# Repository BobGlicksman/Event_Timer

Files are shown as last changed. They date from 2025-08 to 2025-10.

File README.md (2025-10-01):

# Event_Timer
Device to automatically publish Particle events based upon time-based schedules.

## OVERVIEW.
The Event Timer is a standalone component that is intended to be used to automate other projects that are based upon Particle (particle.io) IoT devices.  The Event Timer keeps accurate local time and can run very complex schedules for time-based events.  Upon reaching the date/time for each event, the Event Timer publishes an event to the Particle Cloud.  Particle-based subscribers can then subscribe to the published event and execute a suitable function based upon the event’s data.

The Event Timer software uses the Particle *LocalTimeRK* library to handle all of the complexities of timekeeping, timezone and DST conversion, flexible scheduling, and schedule management.  This library is used by the Event Timer software to:

-	Set up and maintain the current date/time in a localized manner, i.e. properly adjusted for the local timezone and daylight savings time (if applicable).
  
-	Perform date/time format conversions for a human readable display on the Event Timer LCD display panel.
  
-	Create and utilize schedules to determine the date/time of events that are to be published to the Particle Cloud.  Very complex schedules can be specified using the *LocalTimeRK* library.
  
-	Manage several schedules in order to publish different events (or at least the same event with different event data) that trigger different actions by the subscribers.

In addition to publishing events to the Particle Cloud, the Event Timer software:

-	Displays the current date/time on a 2 line, 16 character LCD display panel.
  
-	Displays the date/time of the next upcoming event (of all schedules that it manages) on a 2 line, 16 character LCD display panel.
  
-	Adjusts for daylight savings time and indicates, via an LED, whether the displayed date/time is daylight savings time or standard time.
  
-	Indicates when an event is being published by flashing an LED.
  
-	Indicates when the Event Timer is powered up, initialized, and connected to the Internet.  Internet connection is essential (1) because the Event Timer keeps accurate time by acquiring the current time (in UTC) from the Internet via the Particle Time.now() function, and (2) Particle publish/subscribe is Internet based.

## CONTENTS OF THIS REPOSITORY.
### Top Level.
- **README.md**:  This document.

- **Terms_of_Use_License_and_Disclaimer.pdf**:  Requirements and restrictions for use of the material in this Repository.

- **Event_Timer_Overview_Document.pdf**:  Document that provides an overview of the Event Timer system application, hardware and software.

### Case:  
Folder containing Fusion 360 CAD files for the Event Timer enclosure.

### Software:
Folder containing software source code.

- **TestCode/Photon2 test code**:  Legacy source code for development purposes only.  NOT THE RELEASED SOFTWARE.

- **ParticleFirmware/Event_Timer_Firmware**:  The released Event Timer software.

### Documentation:
Folder containing relevant documentation.

- **Event_Timer_Software_Manual.pdf**:  Document containing details of the Event Timer Software and use of the *LocalTimeRK* library.

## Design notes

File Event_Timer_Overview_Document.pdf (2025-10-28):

# Event Timer Overview Document

By: Jim Schrempp and Bob Glicksman; v1.1, 10/28/2025

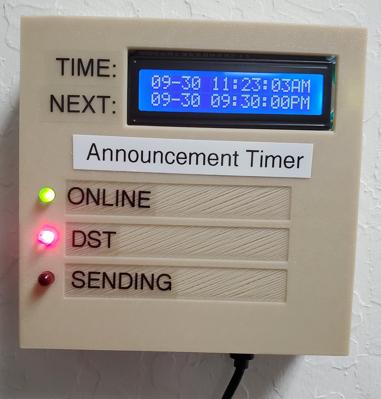
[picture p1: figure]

© 2025 Team Practical Projects, Bob Glicksman, and Jim Schrempp. All rights reserved.

NOTICE: Use of this document is subject to the terms of use described in the document
“Terms_of_Use_License_and_Disclai mer” that is included in this release package. This document can be found at:

https://github.com/TeamPracticalProjects/Event_Timer/tree/main/Documents/Terms_of_Use_License_and_Disclaim er.pdf

© 2025, Team Practical Projects, Jim Schrempp and Bob Glicksman; all rights reserved. Subject to “Terms of Use, License and Disclosure”

TABLE OF CONTENTS.

TABLE OF CONTENTS. | 0
DOCUMENT OVERVIEW. | 2
EVENT TIMER SYSTEM OVERVIEW. | 2
EVENT TIMER HARDWARE. | 4
EVENT TIMER USER INTERFACE. | 4
EVENT TIMER ELECTRONICS. | 5
Printed Circuit Board. | 6
LCD DISPLAY. | 7
LEDs. | 7
Wiring. | 7
EVENT TIMER ENCLOSURE. | 8
EVENT TIMER SOFTWARE. | 8

DOCUMENT OVERVIEW.

This document describes the Event Timer project from Team Practical Projects. The Event Timer is a standalone component that is intended to be used to automate other projects that are based upon Particle¹
IoT devices. The Event Timer keeps accurate local time and can run very complex schedules for time-based events. Upon reaching the date/time for each event, the Event Timer publishes an event to the Particle Cloud. Particle-based subscribers can then subscribe to the published event and execute a suitable function based upon the event’s data.

The Event Timer has been deployed at Maker Nexus as an “Announcement Timer”. Maker Nexus is a 501(c)(3) educational non-profit maker space located in Sunnyvale CA. Maker Nexus has a Help System²

that includes Annunciators³ located throughout the facility. The Annunciators play pre-recorded announcements through internal loudspeakers. Audio announcement clips are included that play closing time announcements. The Event Timer publishes events to the Particle Cloud that are subscribed to by all of the Annunciators. The Event Timer software includes schedules that are pre-defined based upon closing time rules established by Maker Nexus management.

This document provides an overview of the Event Timer as a component of a Particle-based system. It also describes the hardware and software for the Event Timer.

EVENT TIMER SYSTEM OVERVIEW.

Figure 1 is an overview of the use of an Event Timer in a Particle-based IoT system. There is normally one Event Timer in a system. A “system” would normally consist of all Particle based devices that are deployed at a single location over which there are a series of date/time-based rules for routine operation.

When it is time for a scheduled event, the Event Timer publishes an event to the Particle Cloud. Other Particle-based devices (in the same Particle account) can subscribe to this event and execute their functionality accordingly.

Figure 1 shows two such subscribers. An Annunciator may subscribe to an event and play a pre-recorded audio clip based upon the event’s data. A project based upon the Team Practical

1 Particle.io

2 https://github.com/TeamPracticalProjects/MN_Help_System

3 https://github.com/TeamPracticalProjects/Annunciator

Projects Wireless I/O Board⁴
could subscribe to one or more events and control devices such as lights and electronic locks accordingly.

In addition to Particle-based subscribers, a Particle Webhook can be created that subscribes to Event Timer events and uses a Google Apps Script to log these to a Google sheet. The specifics of what is logged in this manner is project dependent. A description of this process can be found at:

https://github.com/TeamPracticalProjects/Connectivity_Tools_with_Particle_Devices

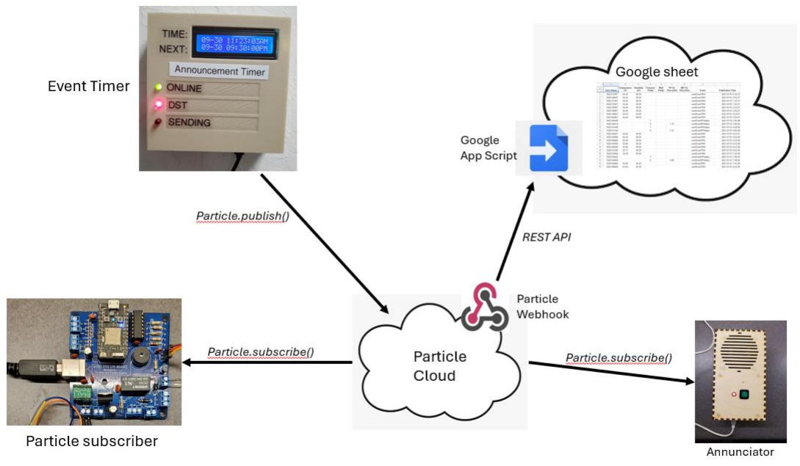
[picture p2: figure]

Figure 1. Event Timer System Overview.

The Event Timer software uses the Particle LocalTimeRK library to handle all of the complexities of timekeeping, timezone and DST conversion, flexible scheduling, and schedule management. This library is used by the Event Timer software to:

- Set up and maintain the current date/time in a localized manner, i.e. properly adjusted for the local timezone and daylight savings time (if applicable).
- Perform date/time format conversions for a human readable display on the Event Timer LCD display panel.

4 https://github.com/TeamPracticalProjects/Wireless_IO_Board

- Create and utilize schedules to determine the date/time of events that are to be published to the Particle Cloud. Very complex schedules can be specified using the LocalTimeRK library.
- Manage several schedules in order to publish different events (or at least the same event with different event data) that trigger different actions by the subscribers.

In addition to publishing events to the Particle Cloud, the Event Timer software:

- Displays the current date/time on a 2 line, 16 character LCD display panel.
- Displays the date/time of the next upcoming event (of all schedules that it manages) on a 2 line, 16 character LCD display panel.
- Adjusts for daylight savings time and indicates, via an LED, whether the displayed date/time is daylight savings time or standard time.
- Indicates when an event is being published by flashing an LED.
- Indicates when the Event Timer is powered up, initialized, and connected to the Internet. Internet connection is essential (1) because the Event Timer keeps accurate time by acquiring the current time (in UTC) from the Internet via the Particle Time.now() function, and (2) Particle publish/subscribe is Internet based.

EVENT TIMER HARDWARE.

EVENT TIMER USER INTERFACE.

Figure 2 shows the front panel of the Event Timer. There is nothing for the user to control. The Event Timer can be mounted anywhere that there is power and WiFi access. The Event Timer is powered via a USB cable connected directly to its Photon 2 USB connector. The other end of the USB cable needs to be connected to a 5 volt USB power supply.

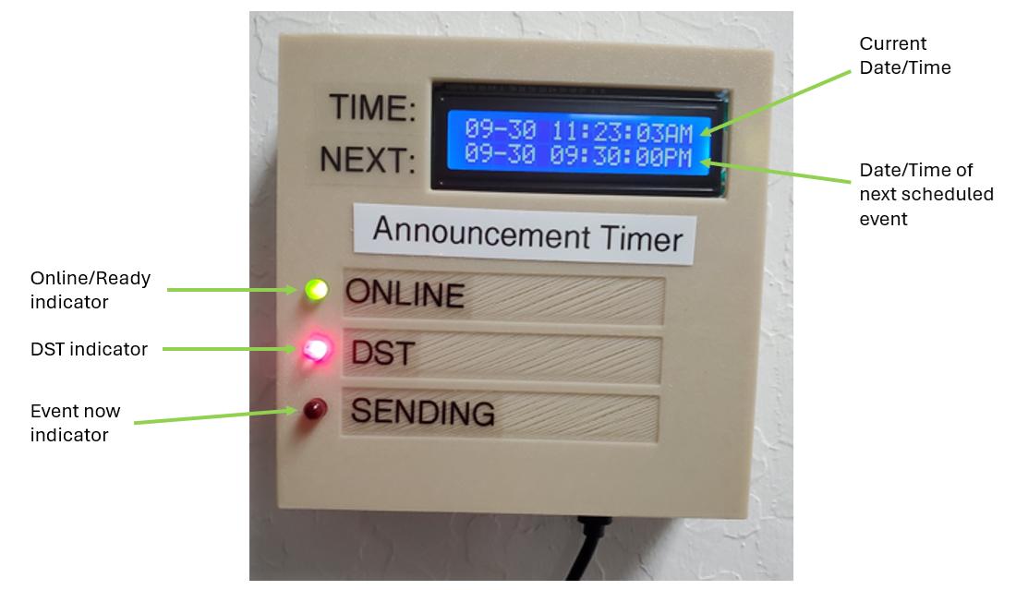
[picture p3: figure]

Figure 2. Event Timer Front Panel.

Referring to figure 2:
- The top line of the 2 line LCD display shows the current date and time. This display is in local time and reflects daylight savings time, as applicable.
- The second line of the 2 line LCD display shows the date and time of the next scheduled event in the Event Timer’s set of schedules.
- An LED (green) indicates that the Event Timer is Online. Online means that the Event Timer is powered on, is connected to the Internet, is synchronized with Internet time, is initialized and is processing the internal list of events and is ready to publish an event to the Particle Cloud.
- An LED (white/yellow) is lit if the current time in the locale is daylight savings time (DST). It is unlit if the current local time is standard time.
- An LED (red) is normally unlit but lights up briefly whenever an event is published to the Particle Cloud (Sending).

EVENT TIMER ELECTRONICS.

Figure 3 shows the Event Timer electronics:

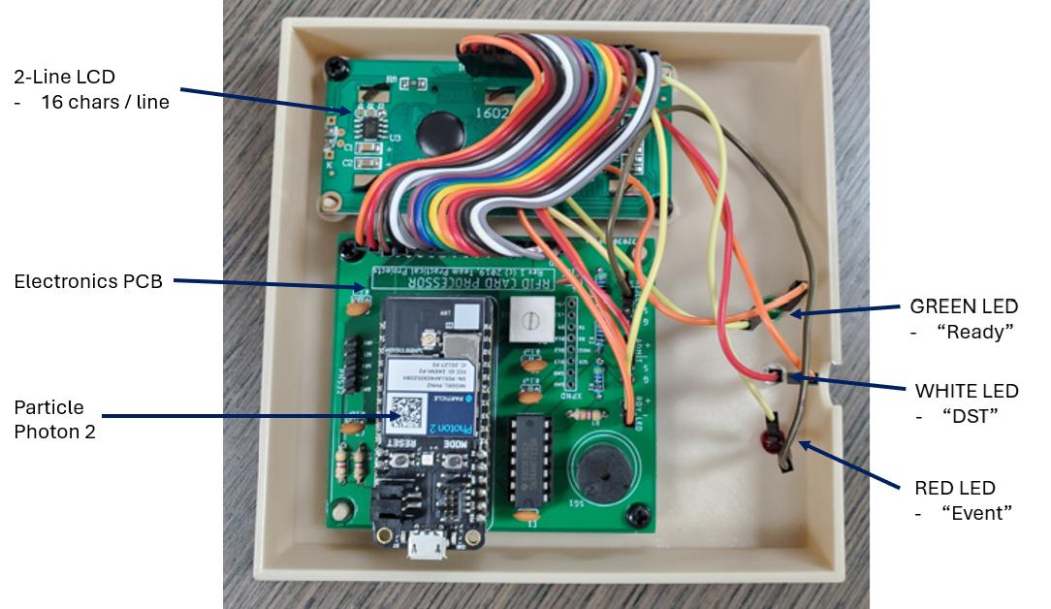
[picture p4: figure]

Figure 3. Event Timer electronics.

All electronic components are mounted onto the back side of the front panel of the Event Timer enclosure. The electronics consist of the following:

- Printed circuit board.
- 2 line, 16 character per line LCD display.
- Three LEDs of differing colors.
- Female pin header jumper cables.

Printed Circuit Board.

The Event Timer uses the same printed circuit board as the Maker Nexus Access Control System RFID Card Stations. A schematic and Cadsoft Eagle source files can be found at:

https://github.com/TeamPracticalProjects/MN_ACL/tree/master/Hardware/PC_board

Note that this board is labeled “RFID Card Processor Rev 1”. Instructions for assembling this printed circuit board can be found in the following document:

https://github.com/TeamPracticalProjects/MN_ACL/blob/master/Hardware/RFID_Station_Build_And_Installation_Instructions.pdf (https://github.com/TeamPracticalProjects/MN_ACL/blob/master/Hardware/RFID_Station_Build_And_Installation_Instructions.pdf)

The printed circuit board should be fully assembled as per the instructions in this document with the following one exception: a Particle Photon 2 is used in lieu of the Particle Argon. The Argon has been deprecated and the Photon 2 is a plug-in replacement. The Photon 2 form factor and pin arrangements are fully compatible with the Argon, however the labeling of some pins differs. The Event Timer software uses the Photon 2 pinout.

Not all of the I/O pins that are brought out to the edge of this printed circuit board are used in the Event Timer. The following pins are used:

- RDY LED. These two pins connect to the “Online” LED. Note the + and – polarity designations.
- ADMIT. Only the pins labelled + and – are used. These are connected to the “DST” LED. Note the + and – polarity designations. The G and S pins are not used.
- REJECT. Only the pins labelled + and – are used. These are connected to the “Sending” LED. Note the + and – polarity designations. The G and S pins are not used.
- 16 pin LCD Connector. These pins are connected, one to one, to the 16 pin connector on the LCD display module.

Note that the 5 pin “PN532” connector is not used in the Event Timer.

LCD DISPLAY.

A 2 line, 16 character per line LCD display is wired, one to one, to the corresponding 16 pins on the printed circuit board. Any generic “1602” LCD display can be used as long as it is 3.3 volt compatible.

LEDs.

Three LEDs of differing colors are used; nominally green, red, and either yellow or white. Any generic LEDs will do. The mounting holes in the Event Timer front panel are sized to accommodate standard 5 mm LEDs.

Wiring.

The printed circuit board external connections all use standard 0.1” spaced male Dupont pin headers. Standard Dupont mating female – female jumper cables can be used to interconnect the printed circuit board with the LCD module and the LEDs. When using these jumpers to connect to the LEDs, the LED leads should be trimmed so that the connector pin body fits firmly on the LED lead. The connections will appear to be mechanically loose; however, they make a decent electrical connection.

EVENT TIMER ENCLOSURE.

3D CAD (Fusion 360) files for the Event Timer enclosure can be found in this repository at:

https://github.com/TeamPracticalProjects/Event_Timer/tree/main/Case

The .stl files can be exported to a 3D printer slicer program in order to slice them into gcode for 3D printing. Low cost PLA filament can be used, as the enclosure is intended for indoor use.

The enclosure consists of two pieces:

- Event Timer Back: This is the rear of the enclosure. It is intended to be screwed onto a wall.
- Event Timer Front: This is the front face of the enclosure onto which the electronic components are mounted. The Front is fitted to the Back of the enclosure. If the fit is loose then M3 screws can be used in the sides to hold it together.

EVENT TIMER SOFTWARE.

The power of the Event Timer is in its software. The software will need to be modified for use with any particular project. To this end, a separate manual is provided that describes the Event Timer Software in great detail; see:

https://github.com/TeamPracticalProjects/Event_Timer/blob/main/Documentation/Event_Timer_Software_Manual.pdf (https://github.com/TeamPracticalProjects/Event_Timer/blob/main/Documentation/Event_Timer_Software_Manual.pdf)

This software is compiled and linked to the LocalTimeRK library using either the Particle Web IDE or the Particle Workbench IDE. The executable software is then Over-the-Air flashed to the Event Timer’s Photon 2 processor.

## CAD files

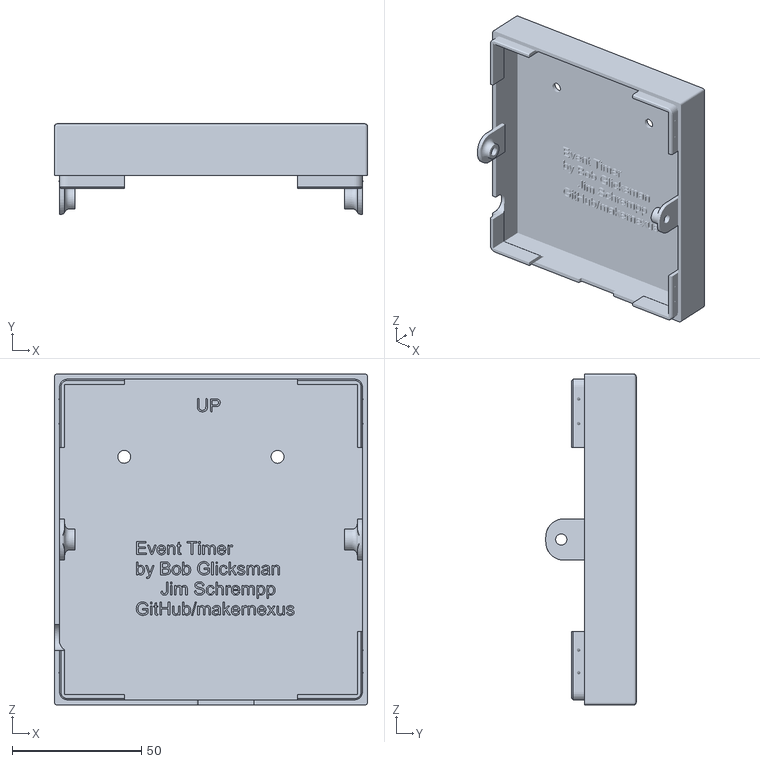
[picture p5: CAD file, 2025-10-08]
Case/event timer back.stl
121.1 x 35.0 x 128.0

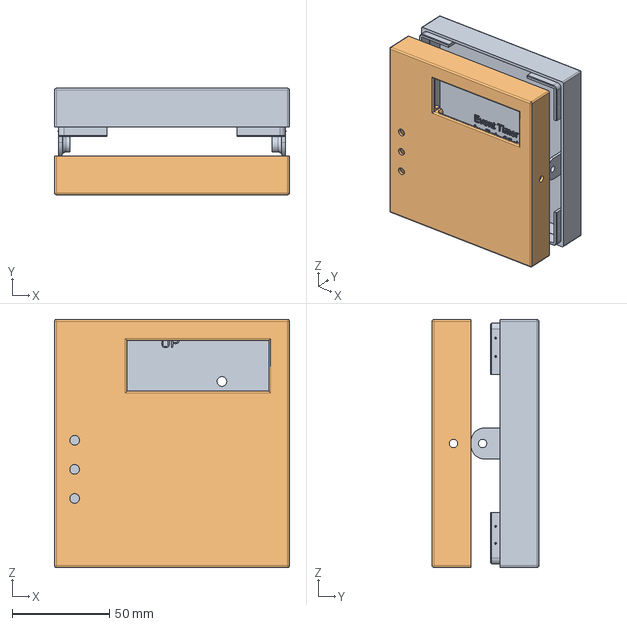
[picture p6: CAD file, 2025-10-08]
Case/event timer box v24.step
121.1 x 55.0 x 128.0 mm

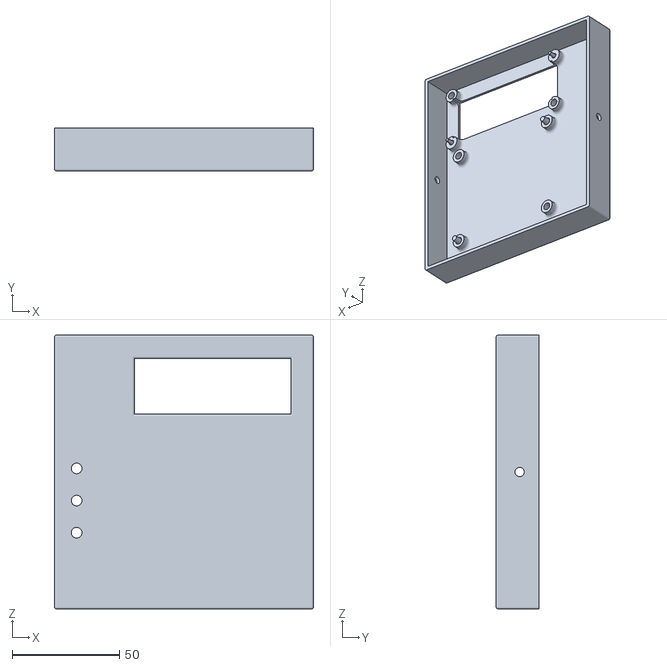
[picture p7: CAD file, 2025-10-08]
Case/event timer front.stl
121.1 x 20.0 x 128.0

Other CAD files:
Case/event timer box v24.f3d

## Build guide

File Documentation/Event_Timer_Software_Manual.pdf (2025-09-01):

# Event Timer Software Manual

By: Jim Schrempp and Bob Glicksman; v1, 9/01/2025

© 2025 Team Practical Projects, Bob Glicksman, and Jim Schrempp. All rights reserved.

NOTICE: Use of this document is subject to the terms of use described in the document “Terms_of_Use_License_and_Disclaimer” that is included in this release package. This document can be found at:

https://github.com/TeamPracticalProjects/Event_Timer/tree/main/Documents/Terms_of_Use_License_and_Disclaimer.pdf

© 2025, Team Practical Projects, Jim Schrempp and Bob Glicksman; all rights reserved. Subject to “Terms of Use, License and Disclosure”

TABLE OF CONTENTS.

TABLE OF CONTENTS. | 1
DOCUMENT OVERVIEW. | 2
SOFTWARE OVERVIEW. | 2
Software Concepts. | 2
LocalTimeRK Library. | 3
Time Conversion and Formatting. | 4
Time Schedules. | 5
Schedule Manager. | 6
LiquidCrystal Library. | 6
Event Publication. | 7
SOFTWARE DETAILS. | 7
Includes and Defines. | 8
Functions. | 8
Setup(). | 9
Loop(). | 10
NOTES ON GENERATING SCHEDULES. | 11
Example: Create two schedules, one daily at 4pm, one only Sunday at 2pm | 11

Example: Create two schedules, one daily at 4pm except Christmas, one only Sunday at 2pm
| 12
NOTE ON VOLATILITY AND PERSISTENCE. | 12

DOCUMENT OVERVIEW.

This document describes the Event Timer software. This software relies on the exceptionally functional LocalTimeRK library to perform all of the complex time conversion functions as well as to create, manage, and use schedules to publish events to the Particle¹ Cloud at pre-scheduled times and dates.

The software in this repository was specifically written to publish events to the Particle Cloud that trigger the Annunciator devices of the Maker Nexus Help System²
to automatically play pre-recorded voice announcements near closing time each day. The purpose of this document is to assist the reader in modifying this software to meet their own, unique event publication requirements.

The Event Timer, the software herein and the LocalTimeRK library are specific to the Particle environment, the Particle Cloud, and the Particle Publish/Subscribe system.

# SOFTWARE OVERVIEW

## Software Concepts

The Event Timer software publishes events to the Particle Cloud based upon pre-determined (in the software) schedules. Each event is subscribed to by external Particle-based devices. Subscribers receive events when they are published and execute an event handler software function that manages the event, according to the event’s data. Projects and products that are based upon Particle IoT devices can have their functions automated by subscribing to an event that is published by this Event Timer.

The management, conversion, formatting, and adjusting of time can be very complex. The setting up and execution of time-based schedules, to publish Particle events at specific times, days, and possibly with specific exceptions, is even more complex. Fortunately, the LocalTimeRK library is available to handle all of this for us. This library is very complex and it takes time to fully understand it and to learn how to utilize its capabilities. A key purpose of this document is to supplement the LocallTimeRK library documentation with an actual project that uses much of this library’s capabilities.

The LocalTimeRK library provides most of the functionality of the Event Timer software. The software described in this document uses the library to do the following:

1 Particle.io
2 https://github.com/TeamPracticalProjects/MN_Help_System

- Set up and maintain the current date/time in a localized manner; i.e. properly adjusted for the local timezone and daylight savings time (if applicable).
- Perform date/time format conversions for a human readable display on the Event Timer LCD display panel.
- Create and utilize schedules to determine the date/time of events that are to be published to the Particle Cloud. Very complex schedules can be specified using the LocalTimeRK library.
- Manage several schedules in order to publish different events (or at least the same event with different event data) that trigger different actions by the subscribers.

In addition to publishing events to the Particle Cloud, the Event Timer software:
- Displays the current date/time on a 2 line, 16 character LCD display panel.
- Displays the date/time of the next scheduled event, of all schedules that it manages, on a 2 line, 16 character LCD display panel.
- Adjusts for daylight savings time and indicates, via an LED, whether the displayed date/time is daylight savings time or standard time.
- Indicates when an event is being published by flashing an LED.
- Indicates when the Event Timer is powered up, initialized, and connected to the Internet. Internet connection is essential because the Event Timer keeps accurate time by acquiring the current time (in UTC) from the Internet via the Particle Time.now() function.

## LocalTimeRK Library

The LocalTimeRK library does all of the “heavy lifting” for time management, time conversion, time formatting, schedule setting, and schedule management. This library is part of the Particle environment and can be included in any project using either the Particle Web IDE or the Particle Workbench.

Online documentation for the LocalTimeRK library can be found at:

https://rickkas7.github.io/LocalTimeRK/index.html

According to this documentation, the library is applicable for:

- Managing local time, and daylight saving time, if needed, on devices in a known location
- Mostly intended for devices in your own home
- Managing scheduling of tasks at a specific local time
- Displaying local time

The main features of this library are:
- Timezone configuration using a POSIX timezone rule string
- Does not require network access to determine timezone and daylight saving transitions
- Good for displaying local time, such as on clock-like devices

- Good for scheduling operations at a specific local time. For example, every day at 8:00 AM regardless of timezone and DST
- Support for locations with DST and without DST (timezone only)
- Should work in the southern hemisphere were DST is opposite on the calendar
- Should work in any country as long as a compatible POSIX timezone configuration string can be generated

The LocalTimeRK library is open source and can be found at:

https://github.com/rickkas7/LocalTimeRK

### Time Conversion and Formatting

The LocalTimeRK automatically uses the Particle Time.now() function to obtain the correct current time from the Internet. This Internet time is in UTC format and the library performs all calculations in UTC for performance reasons. However, the library user can communicate with the library in local time, using the library’s built-in time conversion functionality.

Conversion from UTC to local time is specified in POSIX standard format. This format is described in detail in the library’s on-line documentation. It is easy to read and understand. For example, a local time instance that maintains the local time in the U.S. Pacific timezone that observes US daylight savings time is established in the software via the following one line of code:

LocalTime::instance().withConfig(LocalTimePosixTimezone("PST8PDT,M3.2.0/2:00:00, M11.1.0/2:00:00"));

Similarly, conversion of the library’s internal time format to a human readable format is easily performed. The following one line of code converts the time that is encapsulated in the “conv” object to month, day, hour, minute, second displayable format:

msg = conv.format("%m-%d %I:%M:%S%p");

Where msg is a String and conv is an instance of the library’s LocalTimeConvert class.

Note that the line of code above can also include the year. We did not include year in the displayable message String due to limitations on the line size of the LCD display used in the Event Timer.

Consult the library’s on-line documentation for further details:

https://rickkas7.github.io/LocalTimeRK/index.html

### Time Schedules

One fantastic feature of the LocalTimeRK library is that it can set up and execute schedules. A summary of this library functionality is extracted from the on-line documentation:

…, it's designed to handle scheduling. For example, say you want to perform an operation at 3:00 AM every day, local time. The class can find the UTC time corresponding to this, taking into account timezones and DST changes. Using Time.now() comparisons (at UTC) is fast and efficient. It's also good when you want to store the desired time in EEPROM, retained memory, or the file system.

The library also handles weird transition scenarios that occur on spring forward (in the north hemisphere) where the hour from 2:00 AM local time to 2:59:59 doesn't exist, and in the fall back where the hour from 1:00:00 to 1:59:59 local time occurs twice.
It also handles other common scheduling scenarios:
- Tomorrow (same time)
- Tomorrow (at a specific local time)
- On a specific day of week at a specific time ("every Saturday at 3:00 AM")
- On a day of week with an ordinal ("on the 2nd Saturday of the month")
- On a specific day of month at a specific time
- Also the last day of the month, the second to last day of the month, ...
- On the next weekday (Monday - Friday)
- On the next weekend day (Saturday - Sunday)

Schedules are instances of the library’s LocalTimeSchedule class. There are many helper classes and subclasses in the library that are used to set up and query schedules. The library handles an extremely wide variety of scheduling scenarios that can handle almost any scheduling requirement, including:
- Minute of hour
- Hour of day multiples
- Day of week of the month
- Day of month
- Restricted date ranges
- Exceptions

From the on-line documentation, examples of scheduling include:
- "At 17:00:00" every day (local time)
- "At 17:00:00, Monday - Friday"
- "At 09:00:00, Monday - Friday, except for 2022-03-21"
- "At 23:59:59 on 2022-03-31"

Schedules are so flexible that the on-line documentation is lengthy and dense. However, it is well worth the time to read through and understand all that this library can do:

https://rickkas7.github.io/LocalTimeRK/index.html

Schedule objects have a great many methods associated with them. Some important methods are:
- schedule.isScheduledTime(): determine if it is time to run the scheduled task based upon the current time.
- schedule.getNextScheduledTime(conv): Modify the “conv” object (instance of the library’s LocalTimeConvert class) to encapsulate the time for the next event in the schedule. NOTE: the reference for the event time before the “next” event time is passed in via the conv object, so be sure to initialize “conv” to the current time, or whatever time you need to be the reference, before calling this method.

Schedule Manager.

One class in the LocalTimeRK library that is not well described in the on-line documentation is the LocalTimeScheduleManager. Instances of this class hold multiple named schedules in a C++ vector. The key method associated with this class is:

- schedule.forEach() {}: loops through the manager and returns each schedule object in the manager. The code to execute methods on each schedule in the manager is placed inside the curly brackets.

Schedules are added to the manager in a somewhat obscure way. The LocalTimeScheduleManager class does not have methods like addSchedule(), removeSchedule() etc. Rather, you add or modify a schedule in the schedule manager using the manager.getScheduleByName(String name) method. This method returns a bool indicating whether the named schedule exists in the manager. If the named schedule does not exist in the manager, then it is automatically added to the manager. For example, code to add a schedule to an instance of the LocalTimeScheduleManager class called MNScheduleManager is:

MNScheduleManager.getScheduleByName("13")
.withTime(LocalTimeHMSRestricted(
LocalTimeHMS("21:30:00"),
LocalTimeRestrictedDate(LocalTimeDayOfWeek::MASK_ALL)
));

This code adds or updates a schedule named “13” to the MNScheduleManager object. This schedule will return true on a call to the .isScheduledTime() method on the first call to this method after 9:30 pm (21:30) local time every day.

## LiquidCrystal Library

The venerable Arduino LiquidCrystal library has long been ported into the Particle environment. This library makes it easy to use character-oriented LCD display devices, of which there exist many different modules with different numbers of characters per line and different numbers of lines. This library allows a programmer to print to the LCD in the same manner as printing to a Serial port.

The Event Timer uses a 2 line, 16 character per line LCD to display the current time (top line) and the time of the next scheduled event (bottom line). This display is not essential to the functioning of the Event Timer. However, it is helpful to see that the Event Timer is working properly.

## Event Publication

The end product of the Event Timer are publications to the Particle Cloud of events; each event according to a managed schedule(s). Particle.publish() statements are used to publish events to the Particle Cloud. Published events contain an event name and event data. Subscribers subscribe to events by the event name and receive the event data for further processing. Coding can be as simple as placing an appropriate Particle.publish() statement inside of the code block for a schedule.isScheduledTime() statement which itself is inside of a manager.forEach() loop block of code.

The software that is in this repository includes two functions that use the schedule name of the returned schedule (in the manager.forEach() loop) to generate a data string for the event data. These functions are: simulateSensor() and logToParticle(). These particular functions are specific to a project and would be removed/replaced in any other application of the Event Timer.

Note that the software in this repository obtains the name of the schedule for which the present time is a scheduled time and passes this name to the simulateSensor() function. This software structure allows more complex processing of the event publication to be encapsulated into its own function.

# SOFTWARE DETAILS

The Event Timer software source code can be found in this repository at:

https://github.com/TeamPracticalProjects/Event_Timer/blob/main/Software/ParticleFirmware/Event_Timer_Firmware/src/Event_Timer_Firmware.cpp (https://github.com/TeamPracticalProjects/Event_Timer/blob/main/Software/ParticleFirmware/Event_Timer_Firmware/src/Event_Timer_Firmware.cpp)

This software is specific to a project. The software would be modified in several ways when the Event Timer is used on another project. The purpose of this section is to walk through the software line by line so that the Reader can understand it well enough to make the necessary modifications.

## Includes and Defines

Line 1: #include “application.h” is automatically added by the Particle Workbench. It may be moved below the introductory comments so that it is with the other #include statements.

Line 45: SYSTEM_MODE(AUTOMATIC) is the default system mode and is therefore probably redundant. The automatic system mode tasks the Particle device OS to manage the Photon 2’s WiFi connections automatically, without further involvement from our software.

Lines 47 – 49: includes the libraries.

Lines 54 – 57: define the Photon 2 pins that are used for the Event Timer’s LEDs and buzzer. This specific pinout is for the connections made by the printed circuit board used for the Event Timer. This printed circuit board was originally developed for another project and the board is reused here:

https://github.com/TeamPracticalProjects/MN_ACL/tree/master/Hardware/PC_board

Line 60: instantiates an object (“lcd”) of the LiquidCrystal class. The pinouts are those provided on the printed circuit board mentioned above.

Line 63: instantiates the manager object used in this program “MNScheduleManager”. It is an instance of the LocalTimeScheduleManager class.

## Functions

Lines 65 – 73: the function logToParticle() creates a specifically formatted String out of its arguments and publishes a "LoRaHubLogging" event to the Particle Cloud with this String as the event data. This event and its formatted data are specific to the project that the Event Manager was originally created for. It would be removed/replaced for any other project.

Lines 74 – 81. The function simulatedSensor() converts its String argument to an integer and uses this as one of the arguments in this function’s call to logToParticle(). This function is specific to the project that the Event Manager was originally created for. It would be removed/replaced for any other project.

## Setup()

Line 84: Places the version number constant defined in line 51 of the program into a Cloud variable. It is our standard practice to do this so that we can use the Particle Console to read out the version of software that is actually flashed onto our Particle devices.

Lines 86 – 94: Sets up the Photon 2 pins that drive the LEDs and buzzer to outputs and sets all of these pins to LOW for initialization.

Lines 97 - 105: set up the lcd and initially loads “ ------------” into the two lines of the display. This is to ensure that the times are not displayed until the Photon 2 connects to the Internet for time initialization; in other words, so that an incorrect time is not displayed.

Lines 108 – 110: wait until the Photon 2 is connected to the Internet so that its time can be properly set.

Line 117: this line of code sets up the internal time conversion to U.S. Pacific time (UTC – 8) and to observe U.S. daylight savings time. It also creates an instance of the LocalTime class that is synchronized with Internet time and is the basic “time now” for the program.

Lines 119 – 149: these lines of code create 4 schedules inside of the previously defined MNScheduleManager object. The schedule names are “13”, “14”, “17” and “15” respectively. These names are project specific – they are later used in the creation of the event data Strings for published events from the Event Timer.

Schedule “13” has a scheduled time of 9:30 pm (21:30:00 hrs) every day. Schedule “14” has a scheduled time of 9:45 pm (21:45:00 hrs) every day. Schedule “17” has a scheduled time of 9:55 pm (21:55:00 hrs) every day. Schedule “15” has a scheduled time of 10:00 pm (22:00:00 hrs) every day.

It is worthwhile to deconstruct one of these statements in order to fully explain the syntax. Here is a deconstruction of Schedule “13”:

MNScheduleManager.getScheduleByName("13")

Adds a schedule named “13” to the MNScheduleManager object.

.withTime(LocalTimeHMSRestricted(
LocalTimeHMS("21:30:00"),

Sets a time (21:30:00 or 9:30 pm) for the schedule in local time units (converted from UTC into Pacific time, daylight savings time adjusted).

LocalTimeRestrictedDate(LocalTimeDayOfWeek::MASK_ALL)
));

Declares that the set time is to be scheduled every day of the week with no exclusions and no date range (i.e. repeats forever).

Lines 152 – 159: set the READY LED on and beep the buzzer to indicate that setup() is complete and all times and schedules are set.

## Loop()

Line 166: creates the object “conv” which is an instance of the LocalTimeConvert class. “conv” is hereafter used to encapsulate a time in UTC format and convert it to local time (Pacific time, adjusted for daylight savings time).

Line 167: uses the “conv” object to convert the current Internet time from UTC into local time.

Lines 170 – 174: uses the method isDST() of the “conv” object to return true if the current local time inside of “conv” is daylight savings time (false if standard time). It sets the ADMIT LED on for DST and off for standard time.

Lines 176 – 180: uses the format() method of the “conv” object to format the current local time into Month – Day _ Hour : Minute : Second format and displays the current time (in this format) on the top line of the LCD.

Lines 182 – 205: this loops through the MNScheduleManager, retrieving each managed schedule, in turn, one schedule on each iteration of the loop. When a schedule in hand, two actions are performed:

- The isScheduledTime() method returns true if the current time is after the next time in the schedule. If true, the schedule name is passed to the simulateSensor() function that ultimately results in the publication of an event to the Particle Cloud with the event data determined by the name of the schedule.
- The “conv” object is reset to the current time and the getNextScheduleTime() method changes the internal time in “conv” to be the next scheduled time for the current schedule. This time is compared with the current earliest time and replaces the latter if earlier. When all schedules in MNScheduleManager have been looped through, “conv” will encapsulate the time of the next scheduled event of all of the schedules in MNScheduleManager.

Lines 208 – 211: use methods of the “conv” object to convert its internal time (which is the earliest next scheduled time of all of the managed schedules) to Month – Day _ Hour : Minute : Second format and display it on the bottom line of the LCD.

Line 213: waits a little while (100 ms) before returning to the top of loop. This prevents the LCD display from flickering while not compromising the timekeeping functions of the program.

# NOTES ON GENERATING SCHEDULES

The LocalTimeRK library’s scheduling capability is extraordinarily powerful and flexible. The downside to this is that it is very complex and takes a lot of time and effort to learn. The on-line documentation contains many examples, but these only scratch the surface of what this library is capable of.

Happily, we have found that Microsoft Copilot AI has an excellent understanding of this library and will generate the code for complex scheduling problems based upon a word description. Below are two examples of Copilot generated code. We have not tested these, but they appear to be correct.

## Example: Create two schedules, one daily at 4pm, one only Sunday at 2pm

LocalTimeScheduleManager manager;

// Daily at 4pm
manager.getScheduleByName("daily_4pm") .withTime(LocalTimeHMSRestricted( LocalTimeHMS("16:00:00"),
LocalTimeRestrictedDate(LocalTimeDayOfWeek::MASK_ALL) ));

// Sunday at 2pm
manager.getScheduleByName("sunday_2pm") .withTime(LocalTimeHMSRestricted(
LocalTimeHMS("14:00:00"),
LocalTimeRestrictedDate(LocalTimeDayOfWeek::MASK_SUNDAY) ));

## Example: Create two schedules, one daily at 4pm except Christmas, one only Sunday at 2pm

LocalTimeScheduleManager manager;

// Daily at 4pm, except Christmas (December 25) manager.getScheduleByName("daily_4pm") .withTime(LocalTimeHMSRestricted(

LocalTimeHMS("16:00:00"),
LocalTimeRestrictedDate(
LocalTimeDayOfWeek::MASK_ALL, {},
{"2025-12-25"} // exceptDates: Christmas )
));

// Sunday at 2pm
manager.getScheduleByName("sunday_2pm") .withTime(LocalTimeHMSRestricted(
LocalTimeHMS("14:00:00"),
LocalTimeRestrictedDate(LocalTimeDayOfWeek::MASK_SUNDAY)
));

# NOTE ON VOLATILITY AND PERSISTENCE

The LocalTimeRK library supports json specification for many of its functions; setting up schedules is an example. This capability means that the Event Timer software could be generalized to allow schedules to be entered from the Console or from an external app using Particle.function() with the json representation of a schedule as the String argument. This approach would obviate our current approach of having to change and re-flash the software anytime there is a change to an Event Timer schedule.

The main downside of this alternative approach is volatility. Anytime the power is lost, even for an instant, the current scheduling information will be lost. An approach to handling this situation is to serialize schedules in the manager and store this as String data in the Photon 2’s file system. The file(s) would be read during startup() and the schedules restored into the manager.

We considered this alternative and we have established (with the help of Copilot) that it is feasible. However, we rejected this approach because of its added complexity and the fact that our requirements for the Event Timer require only very infrequent changes to schedules. We assessed that json representation of schedule information is more complex than the code representation of the same schedules in our software. The external app that generates json encoded schedules from some user friendly GUI would be at least as complex as the LocalTimeRK library, obviating the benefits of using this library in the first place. There would be additional complexity in serializing schedule data into files and deserializing data from files back into schedule objects. And finally, testing of the software and the app would be much more complex, as we would need to test our new code more thoroughly than we feel is necessary for testing the library code.

By coding our schedules directly into the library methods in software, we automatically have non-volatility via the schedules being stored in flash (program) memory on the Photon 2.

Furthermore, we have Copilot as a valuable assistant to generate schedule code from our word specifications.

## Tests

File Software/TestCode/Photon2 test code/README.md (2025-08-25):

# Event_Timer_Firmware

This firmware project was created using [Particle Developer Tools](https://www.particle.io/developer-tools/) and is compatible with all [Particle Devices](https://www.particle.io/devices/).

Feel free to replace this README.md file with your own content, or keep it for reference.

## Table of Contents
- [Introduction](#introduction)
- [Prerequisites To Use This Template](#prerequisites-to-use-this-repository)
- [Getting Started](#getting-started)
- [Particle Firmware At A Glance](#particle-firmware-at-a-glance)
  - [Logging](#logging)
  - [Setup and Loop](#setup-and-loop)
  - [Delays and Timing](#delays-and-timing)
  - [Testing and Debugging](#testing-and-debugging)
  - [GitHub Actions (CI/CD)](#github-actions-cicd)
  - [OTA](#ota)
- [Support and Feedback](#support-and-feedback)
- [Version](#version)

## Introduction

For an in-depth understanding of this project template, please refer to our [documentation](https://docs.particle.io/firmware/best-practices/firmware-template/).

## Prerequisites To Use This Repository

To use this software/firmware on a device, you'll need:

- A [Particle Device](https://www.particle.io/devices/).
- Windows/Mac/Linux for building the software and flashing it to a device.
- [Particle Development Tools](https://docs.particle.io/getting-started/developer-tools/developer-tools/) installed and set up on your computer.
- Optionally, a nice cup of tea (and perhaps a biscuit).

## Getting Started

1. While not essential, we recommend running the [device setup process](https://setup.particle.io/) on your Particle device first. This ensures your device's firmware is up-to-date and you have a solid baseline to start from.

2. If you haven't already, open this project in Visual Studio Code (File -> Open Folder). Then [compile and flash](https://docs.particle.io/getting-started/developer-tools/workbench/#cloud-build-and-flash) your device. Ensure your device's USB port is connected to your computer.

3. Verify the device's operation by monitoring its logging output:
    - In Visual Studio Code with the Particle Plugin, open the [command palette](https://docs.particle.io/getting-started/developer-tools/workbench/#particle-commands) and choose "Particle: Serial Monitor".
    - Or, using the Particle CLI, execute:
    ```
    particle serial monitor --follow
    ```

4. Uncomment the code at the bottom of the cpp file in your src directory to publish to the Particle Cloud! Login to console.particle.io to view your devices events in real time.

5. Customize this project! For firmware details, see [Particle firmware](https://docs.particle.io/reference/device-os/api/introduction/getting-started/). For information on the project's directory structure, visit [this link](https://docs.particle.io/firmware/best-practices/firmware-template/#project-overview).

## Particle Firmware At A Glance

### Logging

The firmware includes a [logging library](https://docs.particle.io/reference/device-os/api/logging/logger-class/). You can display messages at different levels and filter them:

```
Log.trace("This is trace message");
Log.info("This is info message");
Log.warn("This is warn message");
Log.error("This is error message");
```

### Setup and Loop

Particle projects originate from the Wiring/Processing framework, which is based on C++. Typically, one-time setup functions are placed in `setup()`, and the main application runs from the `loop()` function.

For advanced scenarios, explore our [threading support](https://docs.particle.io/firmware/software-design/threading-explainer/).

### Delays and Timing

By default, the setup() and loop() functions are blocking whilst they run, meaning that if you put in a delay, your entire application will wait for that delay to finish before anything else can run. 

For techniques that allow you to run multiple tasks in parallel without creating threads, checkout the code example [here](https://docs.particle.io/firmware/best-practices/firmware-template/).

(Note: Although using `delay()` isn't recommended for best practices, it's acceptable for testing.)

### Testing and Debugging

For firmware testing and debugging guidance, check [this documentation](https://docs.particle.io/troubleshooting/guides/build-tools-troubleshooting/debugging-firmware-builds/).

### GitHub Actions (CI/CD)

This project provides a YAML file for GitHub, automating firmware compilation whenever changes are pushed. More details on [Particle GitHub Actions](https://docs.particle.io/firmware/best-practices/github-actions/) are available.

### OTA

To learn how to utilize Particle's OTA service for device updates, consult [this documentation](https://docs.particle.io/getting-started/cloud/ota-updates/).

Test OTA with the 'Particle: Cloud Flash' command in Visual Studio Code or the CLI command 'particle flash'!

This firmware supports binary assets in OTA packages, allowing the inclusion of audio, images, configurations, and external microcontroller firmware. More details are [here](https://docs.particle.io/reference/device-os/api/asset-ota/asset-ota/).

## Support and Feedback

For support or feedback on this template or any Particle products, please join our [community](https://community.particle.io)!

## Version

Template version 1.0.2

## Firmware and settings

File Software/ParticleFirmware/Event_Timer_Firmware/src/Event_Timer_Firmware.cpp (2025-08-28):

#include "application.h"

/*
  Event Timer
    This code is intended to run on a Particle Photon 2 that is plugged into an RFID Station
    printed circuit board.  This circuit board connects the Photon 2 pins to:

    - a 2 line, 16 character per line, 3.3 volt LCD display that is supported by the Arduino
        LiquidCrystal library.
    - a green LED identified on the circuit board as "ADMIT"
    - a red LED identified on the circuit board as "REJECT"
    - a piezo buzzer identified on the circuit board as "BUZZER"
    - a green (yellow)  LED identified on the circuit board as "READY"

    This code uses the "LocalTimeRK" Particle library for both conversions of utc to local
    time and also to create and manage schedules for firing off events.

    ** the schedules that are loaded into the library's schedule management instance are the current
    (as of this date) schedules for closing time announcements at Maker Nexus.  The Event Manager is
    flexible to the extent that the schedules that are loaded into the schedule manager instance
    can be modified or replaced as needed.  The modified code is then re-flashed to the device in order
    for the new functionality to take effect.

    The top line of the LCD displays the current time, adjusted for the timezone and DST.
    The second line of the LCD displays the time of the next event of all schedules in the schedule
    manager instance.

    The "ADMIT" LED lights when the current time is DST; unlit if the current time is standard time.
    The "REJECT" LED lights briefly when a new event is fired off.  The buzzer also beeps briefly 
    at these times.
    The "READY" LED lights when the device is initialized and running in loop().
    
    (c) 2025 by: Bob Glicksman, Jim Schrempp, Team Practicle Projects; all rights reserved.

    version 1.00 Initial release.
    version 0.9 Pre-release.  The code is fully functional!  It just needs all of the test related
        stuff removed and the formatting cleaned up.
    version 0.5 Pre-release.  The display of the time for the next scheduled event is not
        correct.  UTC times for the next event for all managed schedules seem to be bumped to
        the next day, event if some of the current day scheduled events have not yet happened.
        The actually event publication work -- they fire off at the correct times of the correct day.

 */

SYSTEM_MODE(AUTOMATIC)

#include <Particle.h>
#include <LiquidCrystal.h>
#include <LocalTimeRK.h>

#define VERSION "1.00"

// Pinout Definitions for the RFID PCB
#define ADMIT_LED D19
#define REJECT_LED D18
#define BUZZER D2
#define READY_LED D4

// pinout on LCD [RS, EN, D4, D5, D6, D7];
LiquidCrystal lcd(D11, D12, D13, D14, D5, D6);

// local time schedule manager
LocalTimeScheduleManager MNScheduleManager;

void logToParticle(String message, int deviceNum, String payload, int SNRhub1, int RSSIHub1) {   
    // create a JSON string to send to the cloud
    String data = "message=" + message
        + "|deviceNum=" + String(deviceNum) + "|payload=" + payload 
        + "|SNRhub1=" + String(SNRhub1) + "|RSSIHub1=" + String(RSSIHub1);

    long rtn = Particle.publish("LoRaHubLogging", data, PRIVATE);
}  // end of LogToParticle()

// function to generate a "simulated sensor" received message event to the Particle cloud
int simulateSensor(String sensorNum) {
    int _deviceID = sensorNum.toInt();
    String msg = "EventTimer";
    logToParticle(msg, _deviceID, "dummyPayload", 0, 0);

    return 0;
}   // end of simulatedSensor()

void setup() {
    Particle.variable("version", VERSION);  // make the version available to the Console

    pinMode(ADMIT_LED, OUTPUT);
    pinMode(REJECT_LED, OUTPUT);
    pinMode(BUZZER, OUTPUT);
    pinMode(READY_LED, OUTPUT);

    digitalWrite(ADMIT_LED, LOW);
    digitalWrite(REJECT_LED, LOW);
    digitalWrite(BUZZER, LOW);
    digitalWrite(READY_LED, LOW);

    // set up the LCD's number of columns and rows and clear the display
    lcd.begin(16,2);
    lcd.clear();

    // wait for the device to connect to the Internet
    // put up blanks on the LCD display in the meantime
    lcd.setCursor(0,0);
    lcd.print(" -------------- ");
    lcd.setCursor(0,1);
    lcd.print(" -------------- ");  

    // wait for the device to connect to the Internet
    while(!Particle.connected()) {
        delay(100);
    }

    // set up the current time in local time and clear the display
    lcd.clear();
    lcd.setCursor(0,0);

    // set up the local time (Pacific Time)
    LocalTime::instance().withConfig(LocalTimePosixTimezone("PST8PDT,M3.2.0/2:00:00,M11.1.0/2:00:00"));

    // Daily at 9:30pm device message 13
    MNScheduleManager.getScheduleByName("13")
        .withTime(LocalTimeHMSRestricted(
        LocalTimeHMS("21:30:00"),
        //LocalTimeHMS("10:00:00"),  // for testing
        LocalTimeRestrictedDate(LocalTimeDayOfWeek::MASK_ALL)
    ));

    // Daily at 9:45 device message 14
    MNScheduleManager.getScheduleByName("14")
        .withTime(LocalTimeHMSRestricted(
        LocalTimeHMS("21:45:00"),
        //LocalTimeHMS("10:02:00"),  // for testing
        LocalTimeRestrictedDate(LocalTimeDayOfWeek::MASK_ALL)
    ));

   // Daily at 9:55 device message 17
    MNScheduleManager.getScheduleByName("17")
        .withTime(LocalTimeHMSRestricted(
        LocalTimeHMS("21:55:00"),
        //LocalTimeHMS("10:04:00"),  // for testing
        LocalTimeRestrictedDate(LocalTimeDayOfWeek::MASK_ALL)
    ));

    // Daily at 10:00 device message 15
    MNScheduleManager.getScheduleByName("15")
        .withTime(LocalTimeHMSRestricted(
        LocalTimeHMS("22:00:00"),
        //LocalTimeHMS("10:06:00"),  // for testing
        LocalTimeRestrictedDate(LocalTimeDayOfWeek::MASK_ALL)
    ));

    // indicate that the device is ready
    digitalWrite(READY_LED, HIGH);
    digitalWrite(BUZZER, HIGH);
    delay(100);
    digitalWrite(BUZZER, LOW);
    delay(100);
    digitalWrite(BUZZER, HIGH);
    delay(100);
    digitalWrite(BUZZER, LOW);

} // end of setup()

void loop() {
  
    // display the date and time on the lcd
    LocalTimeConvert conv;
    conv.withCurrentTime().convert();

    // set the DST indicator LED
    if(conv.isDST()) {
        digitalWrite(ADMIT_LED, HIGH);
    } else {
        digitalWrite(ADMIT_LED, LOW);
    }

    String msg;
    // first line of display is the date
    msg = conv.format("%m-%d %I:%M:%S%p"); // 08-25 10:00:00AM
    lcd.setCursor(0,0);
    lcd.print(msg);

    time_t earliestTime = 0;
    // for each schedule in the schedule manager, check if there is an event for now
    MNScheduleManager.forEach([&](LocalTimeSchedule &schedule) {
        if (schedule.isScheduledTime()) {
            // Publish event if scheduled time
            String temp = schedule.name;
            simulateSensor(temp);

            // flash the indicator LED briefly
            digitalWrite(REJECT_LED, HIGH);
            delay(200);
            digitalWrite(REJECT_LED, LOW);
        }

        // Get next scheduled event time for display on the second line of the LCD
        conv.withCurrentTime().convert();   // set conv with the current time for next scheduled event
        schedule.getNextScheduledTime(conv);    // update he conv object with the next scheduled time
        time_t nextTime = conv.time;       // converts conv to a time type
        if(earliestTime == 0) {
            earliestTime = nextTime;
        } else if(nextTime < earliestTime) {
            earliestTime = nextTime; 
        }
    });

    // second line of the display is the time
    conv.withTime(earliestTime).convert();
    msg = conv.format("%m-%d %I:%M:%S%p"); // 08-25 10:00:00AM
    lcd.setCursor(0,1);
    lcd.print(msg);

    delay(100);     // wait a bit before looping back

} // end of loop()

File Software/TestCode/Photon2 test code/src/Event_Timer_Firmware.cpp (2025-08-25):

#include "application.h"

/*
  Hardware Test for Event Timer

    Basic hardware and time library software test using Photon 2 in the RFID Station hardware.

    When defined for HARDWARE_TEST, this code displays some stuff on the LCD display and blinks the LEDs 
    in order to demonstrate that the pin mappings are correct.

    Otherwise, this code sets up the local time and displays the current date and time on the LCD.

    (c) 2025 by: Bob Glicksman, Jim Schrempp, Team Practicle Projects; all rights reserved.

    version 1.0.  Initial release: 08-25-2025

 */


#include <Particle.h>
#include <LiquidCrystal.h>
#include <LocalTimeRK.h>

#define VERSION "1.0"
//#define HARDWARE_TEST   // code to just test the hardware, no time stuff included

 // Pinout Definitions for the RFID PCB
 #define ADMIT_LED D19
 #define REJECT_LED D18
 #define BUZZER D2
 #define READY_LED D4

// pinout on LCD [RS, EN, D4, D5, D6, D7];
LiquidCrystal lcd(D11, D12, D13, D14, D5, D6);

void flashLED(int ledPin);  // function forward declaration

void setup() {
  Particle.variable("version", VERSION);  // make the version available to the Console

  pinMode(ADMIT_LED, OUTPUT);
  pinMode(REJECT_LED, OUTPUT);
  pinMode(BUZZER, OUTPUT);
  pinMode(READY_LED, OUTPUT);

  digitalWrite(ADMIT_LED, LOW);
  digitalWrite(REJECT_LED, LOW);
  digitalWrite(BUZZER, LOW);
  digitalWrite(READY_LED, LOW);

  // set up the LCD's number of columns and rows and clear the display
  lcd.begin(16,2);
  lcd.clear();

  #ifdef HARDWARE_TEST
    lcd.setCursor(0,0);
    lcd.print("EVENT TIMER");
  #else
    lcd.setCursor(0,0);
    // set up the local time (Pacific Time)
    LocalTime::instance().withConfig(LocalTimePosixTimezone("PST8PDT,M3.2.0/2:00:00,M11.1.0/2:00:00"));
  #endif

} // end of setup()

void loop() {
  #ifdef HARDWARE_TEST

    // set the cursor to column 0, line 1
    // (note: line 1 is the second row, since counting begins with 0):
    lcd.setCursor(0, 1);
    // print the number of 4 second intervals since reset:
    lcd.print(millis()/4000);

    flashLED(ADMIT_LED);
    flashLED(REJECT_LED);
    flashLED(READY_LED);
    // flashLED(BUZZER);   // commented out -- too annoying!

    delay(1000);
  #else
  // display the date and time on the lcd
    LocalTimeConvert conv;
    conv.withCurrentTime().convert();
    
    String msg;
    // first line of display is the date
    msg = conv.format("%Y-%m-%d"); // 2025-08-25
    lcd.setCursor(0,0);
    lcd.print(msg);

    // second line of the display is the time
    msg = conv.format("%I:%M:%S%p"); // 10:00:00AM
    lcd.setCursor(0,1);
    lcd.print(msg);

    delay(500);
  #endif

} // end of loop()

void flashLED(int ledPin) {
  if(ledPin == BUZZER) {  // beep only once
    digitalWrite(ledPin, HIGH);
    delay(100);
    digitalWrite(ledPin, LOW);
  } else {
    for(int i = 0; i<3; i++) {  // flash LEDs 3 times
      digitalWrite(ledPin, HIGH);
      delay(100);
      digitalWrite(ledPin, LOW);
      delay(100);
    }
  }
} // end of flashLED()

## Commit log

2025-08-25 Basic structure of repo plus test code
    The test code runs LCD, LEDs and buzzer from a Photon 2 that is plugged into the RFID PCB in order to demonstrate the pin mapping from Argon.
    [Event_Timer_Firmware.cpp]
2025-08-26 Update Event_Timer_Firmware.cpp
    Fixed the bug that got the wrong time for the next scheduled event.
    [Event_Timer_Firmware.cpp]
2025-08-27 Update Event_Timer_Firmware.cpp
    Corrected version
    [Event_Timer_Firmware.cpp]
2025-08-27 Update Event_Timer_Firmware.cpp
    Fixed the last bug. This is pre-release 0.9. It only needs all of the testing code removed and the formatting cleaned up.
    [Event_Timer_Firmware.cpp]
2025-08-28 Update Event_Timer_Firmware.cpp
    fixed up jim's unmerge so that it compiles.
    [Event_Timer_Firmware.cpp]
2025-09-26 added case
    [event timer back.stl, event timer box v20.f3d, event timer box v20.step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]
2025-10-07 update case to be a bit larger
    [event timer back.stl, event timer box v20.f3d, event timer box v20.step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]
